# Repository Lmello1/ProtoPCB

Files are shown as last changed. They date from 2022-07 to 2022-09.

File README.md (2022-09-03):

# ProtoPCB

Business card PCB and pocket Attiny3227 and LED matrix playground. Powered by a CR2032 battery
<p align="middle">
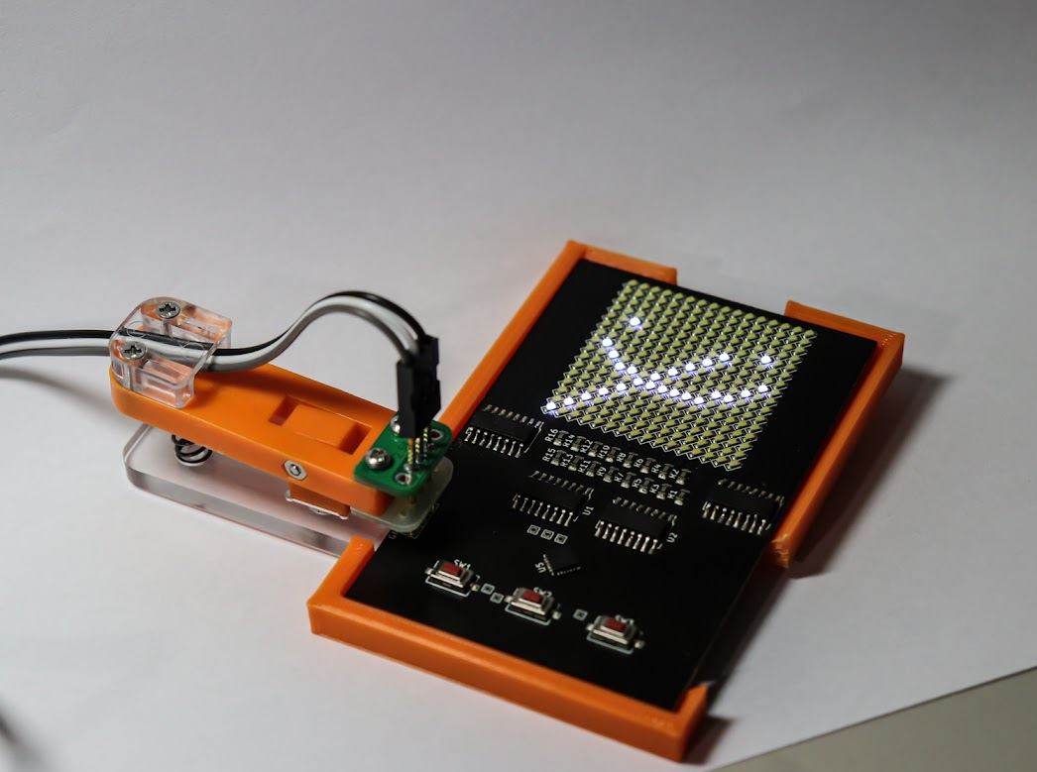
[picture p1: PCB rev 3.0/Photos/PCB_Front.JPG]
  
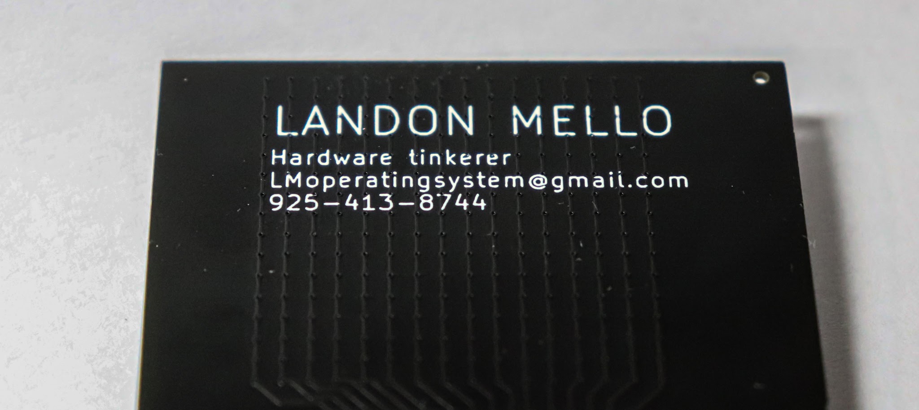
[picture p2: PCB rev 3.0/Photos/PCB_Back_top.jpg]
  
</p>

## Description

A business card PCB based on the ATTINY3227 chipset. Using 4 74HC595D shift registers to drive a 256 LED matrix. With a standard UDPI interface and 3 input buttons the possibilities are endless.
The current code includes various games and demo programs. Please feel free to make your own and share!

NOTE: Shift register U3 is reversed for easier routing.

## Current programs
* Snake

## Coming soon
* Pong
* Tic Tac Toe
* Tetris

## LED matrix info
```
                 led matrix data flow
attiny3227
V
\_________>_______________________>______________________
         U1                      U2                      \
 ____________________    ____________________             |
/                    \  /                    \            |
X  X  X  X  X  X  X  X  X  X  X  X  X  X  X  X \          |
X  X  X  X  X  X  X  X  X  X  X  X  X  X  X  X |          |
X  X  X  X  X  X  X  X  X  X  X  X  X  X  X  X |          |
X  X  X  X  X  X  X  X  X  X  X  X  X  X  X  X |---- U3---V--(REVERSED)
X  X  X  X  X  X  X  X  X  X  X  X  X  X  X  X |          |
X  X  X  X  X  X  X  X  X  X  X  X  X  X  X  X |          |
X  X  X  X  X  X  X  X  X  X  X  X  X  X  X  X |          |
X  X  X  X  X  X  X  X  X  X  X  X  X  X  X  X /          |
X  X  X  X  X  X  X  X  X  X  X  X  X  X  X  X \          |
X  X  X  X  X  X  X  X  X  X  X  X  X  X  X  X |          |
X  X  X  X  X  X  X  X  X  X  X  X  X  X  X  X |          |
X  X  X  X  X  X  X  X  X  X  X  X  X  X  X  X |---- U4   V
X  X  X  X  X  X  X  X  X  X  X  X  X  X  X  X |          |
X  X  X  X  X  X  X  X  X  X  X  X  X  X  X  X |          |
X  X  X  X  X  X  X  X  X  X  X  X  X  X  X  X |          |
X  X  X  X  X  X  X  X  X  X  X  X  X  X  X  X /          *
```

## PCB Revision History
* Rev 1.0 - 1st working version (Do not recreate-one shorted track) NOTE: Removed from github

* Rev 2.0 - Vertical PCB format and visual improvements. Changed foorptints for shift registers

* Rev 3.0 - CR2032 battery holder added for the back, Track routing improvements

## Creators

Landon Mello
[@Landon_Mello](https://twitter.com/Landon_Mello_)

Ben Liebmann

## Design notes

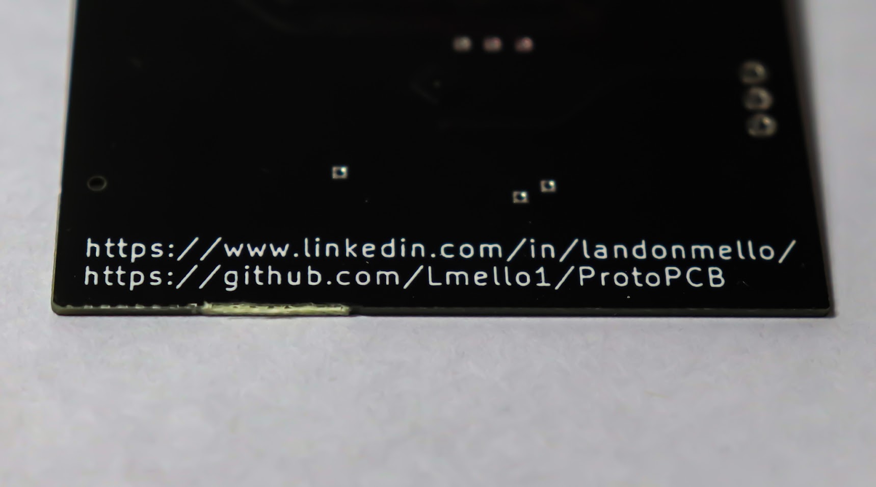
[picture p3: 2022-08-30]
PCB rev 3.0/Photos/PCB_Back_bottom.jpg

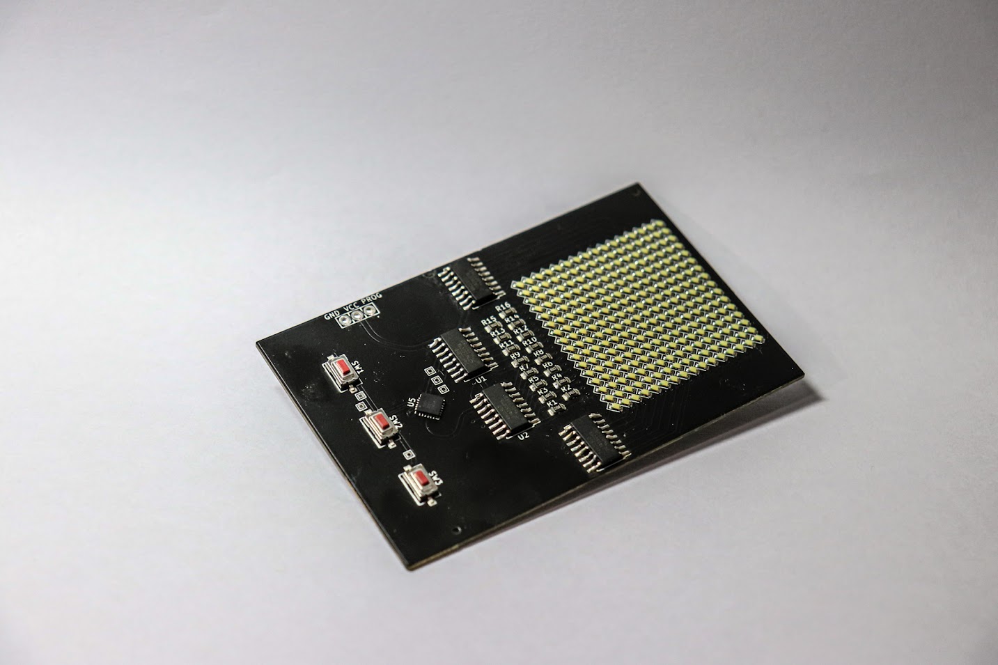
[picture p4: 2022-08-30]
PCB rev 3.0/Photos/PCB_Front_off.JPG

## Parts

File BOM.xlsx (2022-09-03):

 | INV # | Part # | Description | Quantity | Price per |  | Total |  |  |  | INV # | Part # | Description | Quantity | Price per | Total
1 |  | ATTINY3227-MU-ND | Main processer | 1 | 1.772 |  | 1.772 |  |  | 1 |  | ATSAMD20E15B-MU | Main processer mouser | 1 | 2.2896 | 2.2896
2 |  | 74HC595D | Shift registers | 4 | 0.2164 |  | 0.8656 |  |  | 2 |  | 74HC595D | Shift registers | 4 | 0.2164 | 0.8656
3 |  | LED | From china (20k bulk price with shipping) | 256 | 0.00545 |  | 1.3952 |  |  | 3 |  | LED | From china (20k bulk price with shipping) | 256 | 0.00545 | 1.3952
4 |  | 220 ohm resistor |  | 16 | 0.0018 |  | 0.0288 |  |  | 4 |  | 220 ohm resistor |  | 16 | 0.0018 | 0.0288
5 |  | Pushbuttons |  | 3 | 0.0473 |  | 0.1419 |  |  | 5 |  | Pushbuttons |  | 3 | 0.0473 | 0.1419
6 |  |  |  |  |  |  | 0 |  |  | 6 |  |  |  |  |  | 0
7 |  |  |  |  |  |  | 0 |  |  | 7 |  |  |  |  |  | 0
8 |  | PCB |  | 1 | 1.096 |  | 1.096 |  |  | 8 |  | PCB |  | 1 | 1.096 | 1.096
9 |  |  |  |  |  |  | 0 |  |  | 9 |  |  |  |  |  | 0
10 |  |  |  |  |  |  | 0 |  |  | 10 |  |  |  |  |  | 0
11 |  |  |  |  |  |  | 0 |  |  | 11 |  |  |  |  |  | 0
12 |  |  |  |  |  |  | 0 |  |  | 12 |  |  |  |  |  | 0
13 |  |  |  |  |  |  | 0 |  |  | 13 |  |  |  |  |  | 0
14 |  |  |  |  |  |  | 0 |  |  | 14 |  |  |  |  |  | 0
15 |  |  |  |  |  |  | 0 |  |  | 15 |  |  |  |  |  | 0
 |  |  |  |  |  |  | 0 |  |  |  |  |  |  |  |  | 0
 |  |  |  |  |  |  | 5.2995 |  |  |  |  |  |  |  |  | 5.8171
 |  |  | PRICES INCLUDE SHIPPING
 |  |  | Total cost/ cost per unit calculator
 |  |  | Name | Quantity | indv. Cost | Shipping |  | Cost per part | Total cost
1 |  | CPU | 556-ATSAMD20E15B-MU | 25 | 1.97 | 7.99 |  | 2.2896 | 57.24
2 |  | LED | 0603 white LED | 20000 | 0.0035 | 39 |  | 0.00545 | 109
3 |  | SHIFT REGISTERS |  |  |  |  |  | #DIV/0! | 0
4 |  | RESISTOR |  |  |  |  |  | #DIV/0! | 0
5 |  | BUTTONS |  |  |  |  |  | #DIV/0! | 0
6 |  | PCB |  |  |  |  |  | #DIV/0! | 0
7 |  |  |  |  |  |  |  | #DIV/0! | 0
8 |  |  |  |  |  |  |  | #DIV/0! | 0
9 |  |  |  |  |  |  |  | #DIV/0! | 0
10 |  |  |  |  |  |  |  | #DIV/0! | 0
11
12
13
14
15
16
17

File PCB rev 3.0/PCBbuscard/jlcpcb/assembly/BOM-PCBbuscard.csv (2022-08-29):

Comment | Designator | Footprint | LCSC
220 | R1,R10,R11,R12,R13,R14,R15,R16,R2,R3,R4,R5,R6,R7,R8,R9 | R_0805_2012Metric_Pad1.20x1.40mm_HandSolder | C17557
LED | D1,D10,D100,D101,D102,D103,D104,D105,D106,D107,D108,D109,D11,D110,D111,D112,D113,D114,D115,D116,D117,D118,D119,D12,D120,D121,D122,D123,D124,D125,D126,D127,D128,D129,D13,D130,D131,D132,D133,D134,D135,D136,D137,D138,D139,D14,D140,D141,D142,D143,D144,D145,D146,D147,D148,D149,D15,D150,D151,D152,D153,D154,D155,D156,D157,D158,D159,D16,D160,D161,D162,D163,D164,D165,D166,D167,D168,D169,D17,D170,D171,D172,D173,D174,D175,D176,D177,D178,D179,D18,D180,D181,D182,D183,D184,D185,D186,D187,D188,D189,D19,D190,D191,D192,D193,D194,D195,D196,D197,D198,D199,D2,D20,D200,D201,D202,D203,D204,D205,D206,D207,D208,D209,D21,D210,D211,D212,D213,D214,D215,D216,D217,D218,D219,D22,D220,D221,D222,D223,D224,D225,D226,D227,D228,D229,D23,D230,D231,D232,D233,D234,D235,D236,D237,D238,D239,D24,D240,D241,D242,D243,D244,D245,D246,D247,D248,D249,D25,D250,D251,D252,D253,D254,D255,D256,D26,D27,D28,D29,D3,D30,D31,D32,D33,D34,D35,D36,D37,D38,D39,D4,D40,D41,D42,D43,D44,D45,D46,D47,D48,D49,D5,D50,D51,D52,D53,D54,D55,D56,D57,D58,D59,D6,D60,D61,D62,D63,D64,D65,D66,D67,D68,D69,D7,D70,D71,D72,D73,D74,D75,D76,D77,D78,D79,D8,D80,D81,D82,D83,D84,D85,D86,D87,D88,D89,D9,D90,D91,D92,D93,D94,D95,D96,D97,D98,D99 | LED_0603_1608Metric_no_text | C2290
SW_Push | SW1,SW2,SW3 | SW_DIP_SPSTx01_Slide_6.7x4.1mm_W6.73mm_P2.54mm_LowProfile_JPin | C354942
74HC595 | U4 | SOIC127P600X175-16N
74HC595 | U1 | SOIC127P600X175-16N
74HC595 | U3 | SOIC127P600X175-16N
74HC595 | U2 | SOIC127P600X175-16N
ATtiny3217-M | U5 | QFN-24-1EP_4x4mm_P0.5mm_EP2.6x2.6mm_ThermalVias
TestPoint_Probe | TP9 | TestPoint_THTPad_1.0x1.0mm_Drill0.5mm
TestPoint_Probe | TP8 | TestPoint_THTPad_1.0x1.0mm_Drill0.5mm
TestPoint_Probe | TP7 | TestPoint_THTPad_1.0x1.0mm_Drill0.5mm
TestPoint_Probe | TP6 | TestPoint_THTPad_1.0x1.0mm_Drill0.5mm
TestPoint_Probe | TP5 | TestPoint_THTPad_1.0x1.0mm_Drill0.5mm
TestPoint_Probe | TP4 | TestPoint_THTPad_1.0x1.0mm_Drill0.5mm
BAT | U6 | BATHLD001

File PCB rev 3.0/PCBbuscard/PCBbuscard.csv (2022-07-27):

Id | Designator | Package | Quantity | Designation | Supplier and ref
1 | J18,J15,J14,J7 | PinSocket_1x06_P1.27mm_Vertical | 4 | Conn_01x06_Female
2 | J17 | PinHeader_1x07_P2.54mm_Vertical | 1 | VCC
3 | J16 | PinHeader_1x07_P2.54mm_Vertical | 1 | GND
4 | J13,J12,J11,J10,J9,J8,J6,J5,J4,J3,J2,J1 | PinHeader_1x04_P2.54mm_Vertical | 12 | Conn_01x04_Female
5 | D190,D7,D32,D69,D36,D129,D155,D132,D227,D28,D58,D181,D163,D204,D235,D11,D164,D84,D38,D225,D186,D191,D1,D120,D18,D184,D171,D65,D26,D57,D195,D97,D168,D179,D72,D220,D143,D8,D112,D255,D252,D60,D165,D148,D35,D210,D152,D105,D150,D228,D238,D153,D248,D200,D250,D211,D182,D122,D128,D202,D223,D208,D6,D149,D2,D118,D70,D170,D131,D147,D61,D175,D139,D240,D127,D50,D205,D154,D90,D229,D16,D251,D41,D124,D3,D46,D206,D162,D13,D207,D233,D103,D83,D29,D123,D55,D87,D231,D62,D116,D31,D88,D161,D85,D215,D203,D101,D10,D27,D114,D253,D82,D109,D236,D226,D232,D74,D67,D33,D140,D71,D66,D104,D209,D78,D136,D99,D102,D111,D135,D37,D241,D53,D15,D4,D100,D187,D56,D24,D166,D249,D68,D224,D158,D246,D75,D119,D198,D176,D9,D137,D43,D63,D174,D92,D185,D142,D193,D40,D244,D94,D243,D216,D156,D14,D239,D177,D245,D230,D222,D51,D167,D76,D138,D77,D23,D81,D172,D213,D247,D146,D44,D79,D145,D126,D256,D42,D107,D160,D95,D242,D52,D221,D117,D108,D110,D86,D30,D54,D197,D183,D237,D234,D22,D188,D80,D254,D5,D196,D113,D219,D73,D25,D214,D141,D91,D159,D89,D199,D144,D39,D189,D106,D212,D180,D96,D45,D20,D21,D157,D218,D64,D19,D133,D17,D173,D115,D48,D47,D151,D49,D93,D34,D169,D192,D130,D134,D98,D194,D125,D178,D12,D121,D59,D217,D201 | LED_0201_0603Metric NOTEXT | 256 | LED
6 | R12,R7,R2,R9,R11,R6,R8,R13,R10,R3,R5,R1,R4,R15,R14,R16 | R_0805_2012Metric_Pad1.20x1.40mm_HandSolder | 16 | 220
7 | U4,U1,U3,U2 | SOIC-16W_5.3x10.2mm_P1.27mm | 4 | 74HC595
8 | TP3 | TestPoint_Plated_Hole_D2.0mm | 1 | UPDI
9 | SW2,SW3,SW1 | SW_DIP_SPSTx01_Slide_6.7x4.1mm_W6.73mm_P2.54mm_LowProfile_JPin | 3 | SW_Push
10 | TP2 | TestPoint_Plated_Hole_D2.0mm | 1 | GND
11 | U5 | QFN-24-1EP_4x4mm_P0.5mm_EP2.6x2.6mm_ThermalVias | 1 | ATtiny3217-M
12 | TP1 | TestPoint_Plated_Hole_D2.0mm | 1 | VCC

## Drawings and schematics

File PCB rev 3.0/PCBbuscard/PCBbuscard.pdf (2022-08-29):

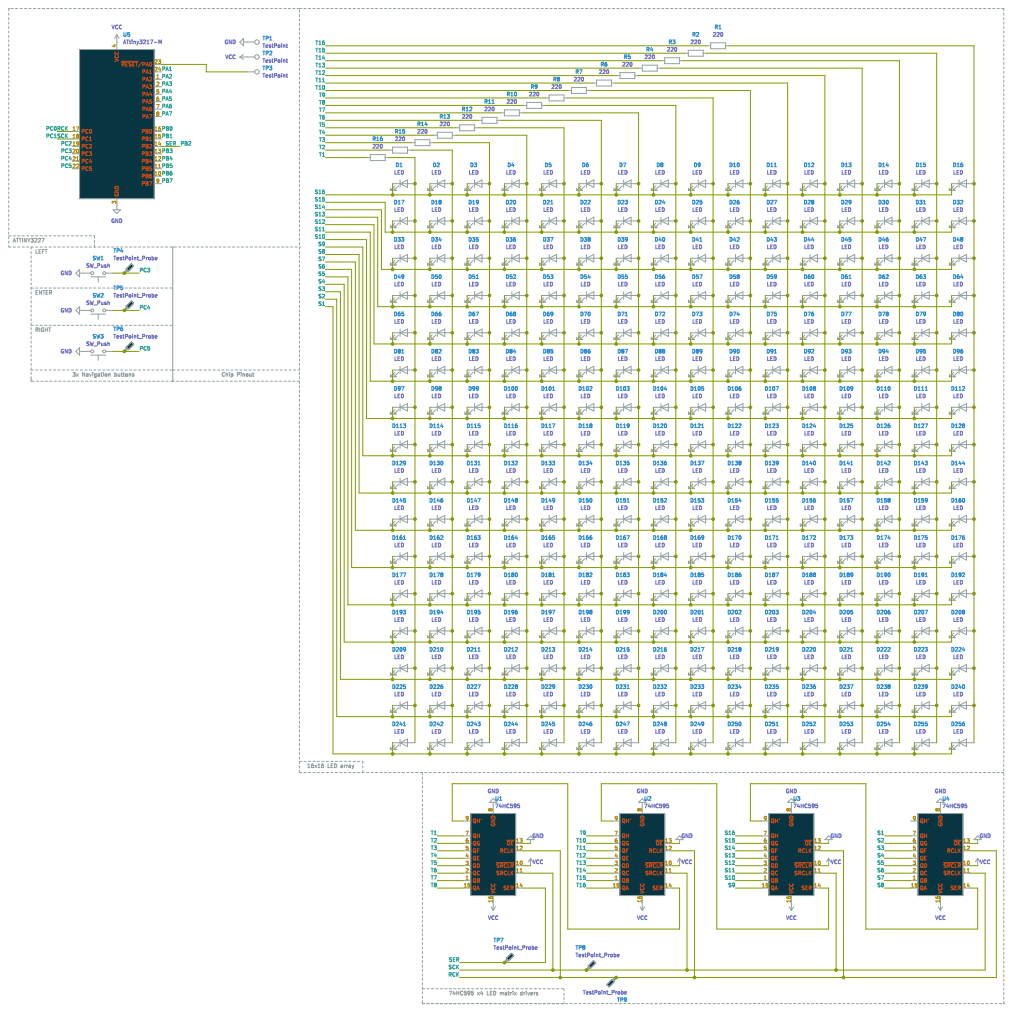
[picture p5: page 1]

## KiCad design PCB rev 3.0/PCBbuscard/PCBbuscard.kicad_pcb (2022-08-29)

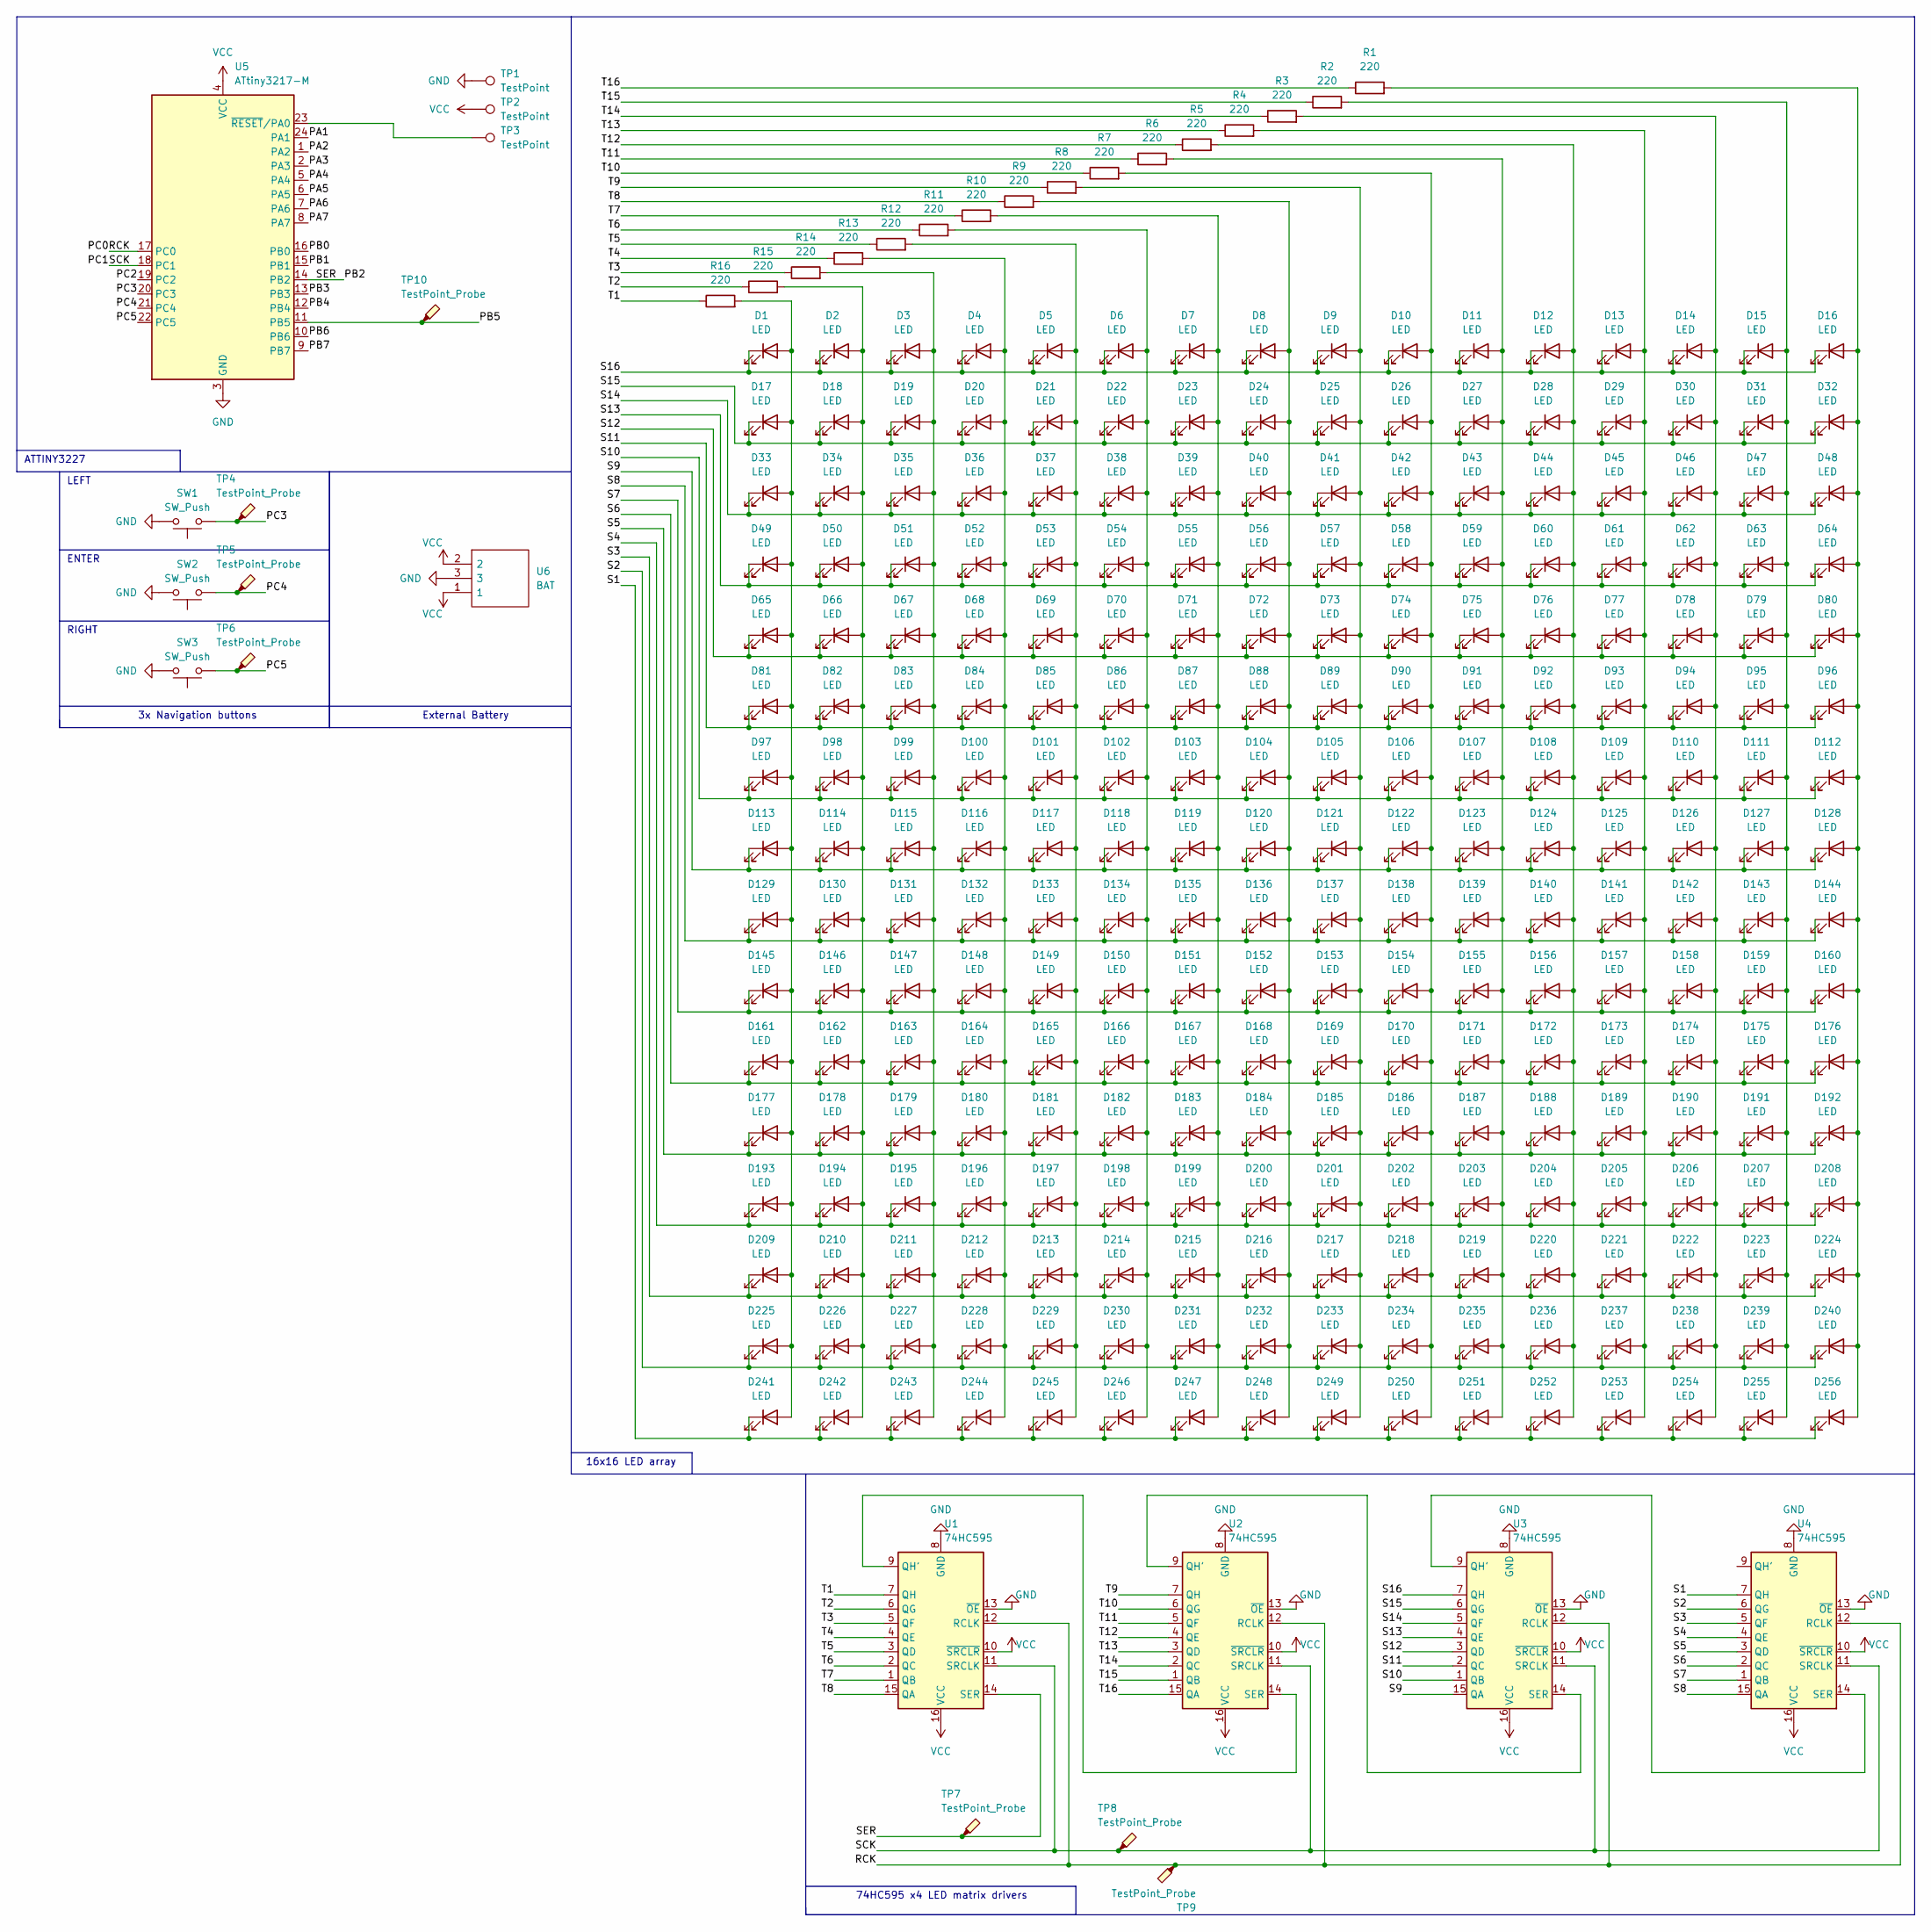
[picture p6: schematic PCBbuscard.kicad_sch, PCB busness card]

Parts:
D1, D2, D3, D4, D5, D6, D7, D8, D9, D10, D11, D12, D13, D14, D15, D16, D17, D18, D19, D20, D21, D22, D23, D24, D25, D26, D27, D28, D29, D30, D31, D32, D33, D34, D35, D36, D37, D38, D39, D40, D41, D42, D43, D44, D45, D46, D47, D48, D49, D50, D51, D52, D53, D54, D55, D56, D57, D58, D59, D60, D61, D62, D63, D64, D65, D66, D67, D68, D69, D70, D71, D72, D73, D74, D75, D76, D77, D78, D79, D80, D81, D82, D83, D84, D85, D86, D87, D88, D89, D90, D91, D92, D93, D94, D95, D96, D97, D98, D99, D100, D101, D102, D103, D104, D105, D106, D107, D108, D109, D110, D111, D112, D113, D114, D115, D116, D117, D118, D119, D120, D121, D122, D123, D124, D125, D126, D127, D128, D129, D130, D131, D132, D133, D134, D135, D136, D137, D138, D139, D140, D141, D142, D143, D144, D145, D146, D147, D148, D149, D150, D151, D152, D153, D154, D155, D156, D157, D158, D159, D160, D161, D162, D163, D164, D165, D166, D167, D168, D169, D170, D171, D172, D173, D174, D175, D176, D177, D178, D179, D180, D181, D182, D183, D184, D185, D186, D187, D188, D189, D190, D191, D192, D193, D194, D195, D196, D197, D198, D199, D200, D201, D202, D203, D204, D205, D206, D207, D208, D209, D210, D211, D212, D213, D214, D215, D216, D217, D218, D219, D220, D221, D222, D223, D224, D225, D226, D227, D228, D229, D230, D231, D232, D233, D234, D235, D236, D237, D238, D239, D240, D241, D242, D243, D244, D245, D246, D247, D248, D249, D250, D251, D252, D253, D254, D255, D256: LED; LED_0603_1608Metric_no_text
R1, R2, R3, R4, R5, R6, R7, R8, R9, R10, R11, R12, R13, R14, R15, R16: 220; R_0805_2012Metric_Pad1.20x1.40mm_HandSolder
SW1, SW2, SW3: SW_Push; SW_DIP_SPSTx01_Slide_6.7x4.1mm_W6.73mm_P2.54mm_LowProfile_J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
TP1, TP2, TP3: TestPoint; Pin_D1.1mm_L8.5mm_W2.5mm_FlatFork
TP4, TP5, TP6, TP7, TP8, TP9: TestPoint_Probe; TestPoint_THTPad_1.0x1.0mm_Drill0.5mm
TP10: TestPoint_Probe; Pin_D1.1mm_L8.5mm_W2.5mm_FlatFork
U1, U2, U3, U4: 74HC595; SOIC127P600X175-16N
U5: ATtiny3217-M; QFN-24-1EP_4x4mm_P0.5mm_EP2.6x2.6mm_ThermalVias
U6: BAT; BATHLD001; Mouser Part Number 712-BAT-HLD-001

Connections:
/PA1: U5.24 (PA1)
/PA2: U5.1 (PA2)
/PA3: U5.2 (PA3)
/PA4: U5.5 (PA4)
/PA5: U5.6 (PA5)
/PA6: U5.7 (PA6)
/PA7: U5.8 (PA7)
/PB0: U5.16 (PB0)
/PB1: U5.15 (PB1)
/PB2: TP7.1, U1.14 (SER), U5.14 (PB2)
/PB3: U5.13 (PB3)
/PB4: U5.12 (PB4)
/PB5: TP10.1, U5.11 (PB5); also elsewhere on the board
/PB6: U5.10 (PB6)
/PB7: U5.9 (PB7)
/PC0: TP9.1, U1.12 (RCLK), U2.12 (RCLK), U3.12 (RCLK), U4.12 (RCLK), U5.17 (PC0)
/PC1: TP8.1, U1.11 (SRCLK), U2.11 (SRCLK), U3.11 (SRCLK), U4.11 (SRCLK), U5.18 (PC1)
/PC2: U5.19 (PC2)
/PC3: SW1.1, TP4.1, U5.20 (PC3)
/PC4: SW2.1, TP5.1, U5.21 (PC4)
/PC5: SW3.1, TP6.1, U5.22 (PC5)
/S1: D241.1 (K), D242.1 (K), D243.1 (K), D244.1 (K), D245.1 (K), D246.1 (K), D247.1 (K), D248.1 (K), D249.1 (K), D250.1 (K), D251.1 (K), D252.1 (K), D253.1 (K), D254.1 (K), D255.1 (K), D256.1 (K), U4.7 (QH)
/S2: D225.1 (K), D226.1 (K), D227.1 (K), D228.1 (K), D229.1 (K), D230.1 (K), D231.1 (K), D232.1 (K), D233.1 (K), D234.1 (K), D235.1 (K), D236.1 (K), D237.1 (K), D238.1 (K), D239.1 (K), D240.1 (K), U4.6 (QG)
/S3: D209.1 (K), D210.1 (K), D211.1 (K), D212.1 (K), D213.1 (K), D214.1 (K), D215.1 (K), D216.1 (K), D217.1 (K), D218.1 (K), D219.1 (K), D220.1 (K), D221.1 (K), D222.1 (K), D223.1 (K), D224.1 (K), U4.5 (QF)
/S4: D193.1 (K), D194.1 (K), D195.1 (K), D196.1 (K), D197.1 (K), D198.1 (K), D199.1 (K), D200.1 (K), D201.1 (K), D202.1 (K), D203.1 (K), D204.1 (K), D205.1 (K), D206.1 (K), D207.1 (K), D208.1 (K), U4.4 (QE)
/S5: D177.1 (K), D178.1 (K), D179.1 (K), D180.1 (K), D181.1 (K), D182.1 (K), D183.1 (K), D184.1 (K), D185.1 (K), D186.1 (K), D187.1 (K), D188.1 (K), D189.1 (K), D190.1 (K), D191.1 (K), D192.1 (K), U4.3 (QD)
/S6: D161.1 (K), D162.1 (K), D163.1 (K), D164.1 (K), D165.1 (K), D166.1 (K), D167.1 (K), D168.1 (K), D169.1 (K), D170.1 (K), D171.1 (K), D172.1 (K), D173.1 (K), D174.1 (K), D175.1 (K), D176.1 (K), U4.2 (QC)
/S7: D145.1 (K), D146.1 (K), D147.1 (K), D148.1 (K), D149.1 (K), D150.1 (K), D151.1 (K), D152.1 (K), D153.1 (K), D154.1 (K), D155.1 (K), D156.1 (K), D157.1 (K), D158.1 (K), D159.1 (K), D160.1 (K), U4.1 (QB)
/S8: D129.1 (K), D130.1 (K), D131.1 (K), D132.1 (K), D133.1 (K), D134.1 (K), D135.1 (K), D136.1 (K), D137.1 (K), D138.1 (K), D139.1 (K), D140.1 (K), D141.1 (K), D142.1 (K), D143.1 (K), D144.1 (K), U4.15 (QA)
/S9: D113.1 (K), D114.1 (K), D115.1 (K), D116.1 (K), D117.1 (K), D118.1 (K), D119.1 (K), D120.1 (K), D121.1 (K), D122.1 (K), D123.1 (K), D124.1 (K), D125.1 (K), D126.1 (K), D127.1 (K), D128.1 (K), U3.15 (QA)
/S10: D97.1 (K), D98.1 (K), D99.1 (K), D100.1 (K), D101.1 (K), D102.1 (K), D103.1 (K), D104.1 (K), D105.1 (K), D106.1 (K), D107.1 (K), D108.1 (K), D109.1 (K), D110.1 (K), D111.1 (K), D112.1 (K), U3.1 (QB)
/S11: D81.1 (K), D82.1 (K), D83.1 (K), D84.1 (K), D85.1 (K), D86.1 (K), D87.1 (K), D88.1 (K), D89.1 (K), D90.1 (K), D91.1 (K), D92.1 (K), D93.1 (K), D94.1 (K), D95.1 (K), D96.1 (K), U3.2 (QC)
/S12: D65.1 (K), D66.1 (K), D67.1 (K), D68.1 (K), D69.1 (K), D70.1 (K), D71.1 (K), D72.1 (K), D73.1 (K), D74.1 (K), D75.1 (K), D76.1 (K), D77.1 (K), D78.1 (K), D79.1 (K), D80.1 (K), U3.3 (QD)
/S13: D49.1 (K), D50.1 (K), D51.1 (K), D52.1 (K), D53.1 (K), D54.1 (K), D55.1 (K), D56.1 (K), D57.1 (K), D58.1 (K), D59.1 (K), D60.1 (K), D61.1 (K), D62.1 (K), D63.1 (K), D64.1 (K), U3.4 (QE)
/S14: D33.1 (K), D34.1 (K), D35.1 (K), D36.1 (K), D37.1 (K), D38.1 (K), D39.1 (K), D40.1 (K), D41.1 (K), D42.1 (K), D43.1 (K), D44.1 (K), D45.1 (K), D46.1 (K), D47.1 (K), D48.1 (K), U3.5 (QF)
/S15: D17.1 (K), D18.1 (K), D19.1 (K), D20.1 (K), D21.1 (K), D22.1 (K), D23.1 (K), D24.1 (K), D25.1 (K), D26.1 (K), D27.1 (K), D28.1 (K), D29.1 (K), D30.1 (K), D31.1 (K), D32.1 (K), U3.6 (QG)
/S16: D1.1 (K), D2.1 (K), D3.1 (K), D4.1 (K), D5.1 (K), D6.1 (K), D7.1 (K), D8.1 (K), D9.1 (K), D10.1 (K), D11.1 (K), D12.1 (K), D13.1 (K), D14.1 (K), D15.1 (K), D16.1 (K), U3.7 (QH)
/T1: R16.1, U1.7 (QH)
/T2: R15.1, U1.6 (QG)
/T3: R14.1, U1.5 (QF)
/T4: R13.1, U1.4 (QE)
/T5: R12.1, U1.3 (QD)
/T6: R11.1, U1.2 (QC)
/T7: R10.1, U1.1 (QB)
/T8: R9.1, U1.15 (QA)
/T9: R8.1, U2.7 (QH)
/T10: R7.1, U2.6 (QG)
/T11: R6.1, U2.5 (QF)
/T12: R5.1, U2.4 (QE)
/T13: R4.1, U2.3 (QD)
/T14: R3.1, U2.2 (QC)
/T15: R2.1, U2.1 (QB)
/T16: R1.1, U2.15 (QA)
GND: SW1.2, SW2.2, SW3.2, TP1.1, U1.8 (GND), U1.13 (~OE), U2.8 (GND), U2.13 (~OE), U3.8 (GND), U3.13 (~OE), U4.8 (GND), U4.13 (~OE), U5.3 (GND), U5.25 (GND), U6.3; also elsewhere on the board
unnamed: D1.2 (A), D17.2 (A), D33.2 (A), D49.2 (A), D65.2 (A), D81.2 (A), D97.2 (A), D113.2 (A), D129.2 (A), D145.2 (A), D161.2 (A), D177.2 (A), D193.2 (A), D209.2 (A), D225.2 (A), D241.2 (A), R16.2
unnamed: D10.2 (A), D26.2 (A), D42.2 (A), D58.2 (A), D74.2 (A), D90.2 (A), D106.2 (A), D122.2 (A), D138.2 (A), D154.2 (A), D170.2 (A), D186.2 (A), D202.2 (A), D218.2 (A), D234.2 (A), D250.2 (A), R7.2
unnamed: D4.2 (A), D20.2 (A), D36.2 (A), D52.2 (A), D68.2 (A), D84.2 (A), D100.2 (A), D116.2 (A), D132.2 (A), D148.2 (A), D164.2 (A), D180.2 (A), D196.2 (A), D212.2 (A), D228.2 (A), D244.2 (A), R13.2
unnamed: D5.2 (A), D21.2 (A), D37.2 (A), D53.2 (A), D69.2 (A), D85.2 (A), D101.2 (A), D117.2 (A), D133.2 (A), D149.2 (A), D165.2 (A), D181.2 (A), D197.2 (A), D213.2 (A), D229.2 (A), D245.2 (A), R12.2
unnamed: D6.2 (A), D22.2 (A), D38.2 (A), D54.2 (A), D70.2 (A), D86.2 (A), D102.2 (A), D118.2 (A), D134.2 (A), D150.2 (A), D166.2 (A), D182.2 (A), D198.2 (A), D214.2 (A), D230.2 (A), D246.2 (A), R11.2
unnamed: D7.2 (A), D23.2 (A), D39.2 (A), D55.2 (A), D71.2 (A), D87.2 (A), D103.2 (A), D119.2 (A), D135.2 (A), D151.2 (A), D167.2 (A), D183.2 (A), D199.2 (A), D215.2 (A), D231.2 (A), D247.2 (A), R10.2
unnamed: D8.2 (A), D24.2 (A), D40.2 (A), D56.2 (A), D72.2 (A), D88.2 (A), D104.2 (A), D120.2 (A), D136.2 (A), D152.2 (A), D168.2 (A), D184.2 (A), D200.2 (A), D216.2 (A), D232.2 (A), D248.2 (A), R9.2
unnamed: D9.2 (A), D25.2 (A), D41.2 (A), D57.2 (A), D73.2 (A), D89.2 (A), D105.2 (A), D121.2 (A), D137.2 (A), D153.2 (A), D169.2 (A), D185.2 (A), D201.2 (A), D217.2 (A), D233.2 (A), D249.2 (A), R8.2
unnamed: D11.2 (A), D27.2 (A), D43.2 (A), D59.2 (A), D75.2 (A), D91.2 (A), D107.2 (A), D123.2 (A), D139.2 (A), D155.2 (A), D171.2 (A), D187.2 (A), D203.2 (A), D219.2 (A), D235.2 (A), D251.2 (A), R6.2
unnamed: D12.2 (A), D28.2 (A), D44.2 (A), D60.2 (A), D76.2 (A), D92.2 (A), D108.2 (A), D124.2 (A), D140.2 (A), D156.2 (A), D172.2 (A), D188.2 (A), D204.2 (A), D220.2 (A), D236.2 (A), D252.2 (A), R5.2
unnamed: D13.2 (A), D29.2 (A), D45.2 (A), D61.2 (A), D77.2 (A), D93.2 (A), D109.2 (A), D125.2 (A), D141.2 (A), D157.2 (A), D173.2 (A), D189.2 (A), D205.2 (A), D221.2 (A), D237.2 (A), D253.2 (A), R4.2
unnamed: D14.2 (A), D30.2 (A), D46.2 (A), D62.2 (A), D78.2 (A), D94.2 (A), D110.2 (A), D126.2 (A), D142.2 (A), D158.2 (A), D174.2 (A), D190.2 (A), D206.2 (A), D222.2 (A), D238.2 (A), D254.2 (A), R3.2
unnamed: D15.2 (A), D31.2 (A), D47.2 (A), D63.2 (A), D79.2 (A), D95.2 (A), D111.2 (A), D127.2 (A), D143.2 (A), D159.2 (A), D175.2 (A), D191.2 (A), D207.2 (A), D223.2 (A), D239.2 (A), D255.2 (A), R2.2
unnamed: D16.2 (A), D32.2 (A), D48.2 (A), D64.2 (A), D80.2 (A), D96.2 (A), D112.2 (A), D128.2 (A), D144.2 (A), D160.2 (A), D176.2 (A), D192.2 (A), D208.2 (A), D224.2 (A), D240.2 (A), D256.2 (A), R1.2
unnamed: D2.2 (A), D18.2 (A), D34.2 (A), D50.2 (A), D66.2 (A), D82.2 (A), D98.2 (A), D114.2 (A), D130.2 (A), D146.2 (A), D162.2 (A), D178.2 (A), D194.2 (A), D210.2 (A), D226.2 (A), D242.2 (A), R15.2
unnamed: D3.2 (A), D19.2 (A), D35.2 (A), D51.2 (A), D67.2 (A), D83.2 (A), D99.2 (A), D115.2 (A), D131.2 (A), D147.2 (A), D163.2 (A), D179.2 (A), D195.2 (A), D211.2 (A), D227.2 (A), D243.2 (A), R14.2
unnamed 70: TP3.1, U5.23 (~RESET/PA0); also elsewhere on the board
unnamed: U1.9 (QH'), U2.14 (SER)
unnamed: U2.9 (QH'), U3.14 (SER)
unnamed: U3.9 (QH'), U4.14 (SER)
VCC: TP2.1, U1.10 (~SRCLR), U1.16 (VCC), U2.10 (~SRCLR), U2.16 (VCC), U3.10 (~SRCLR), U3.16 (VCC), U4.10 (~SRCLR), U4.16 (VCC), U5.4 (VCC), U6.1, U6.2; also elsewhere on the board

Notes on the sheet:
External Battery
ENTER
RIGHT
3x Navigation buttons
74HC595 x4 LED matrix drivers
16x16 LED array
LEFT
ATTINY3227

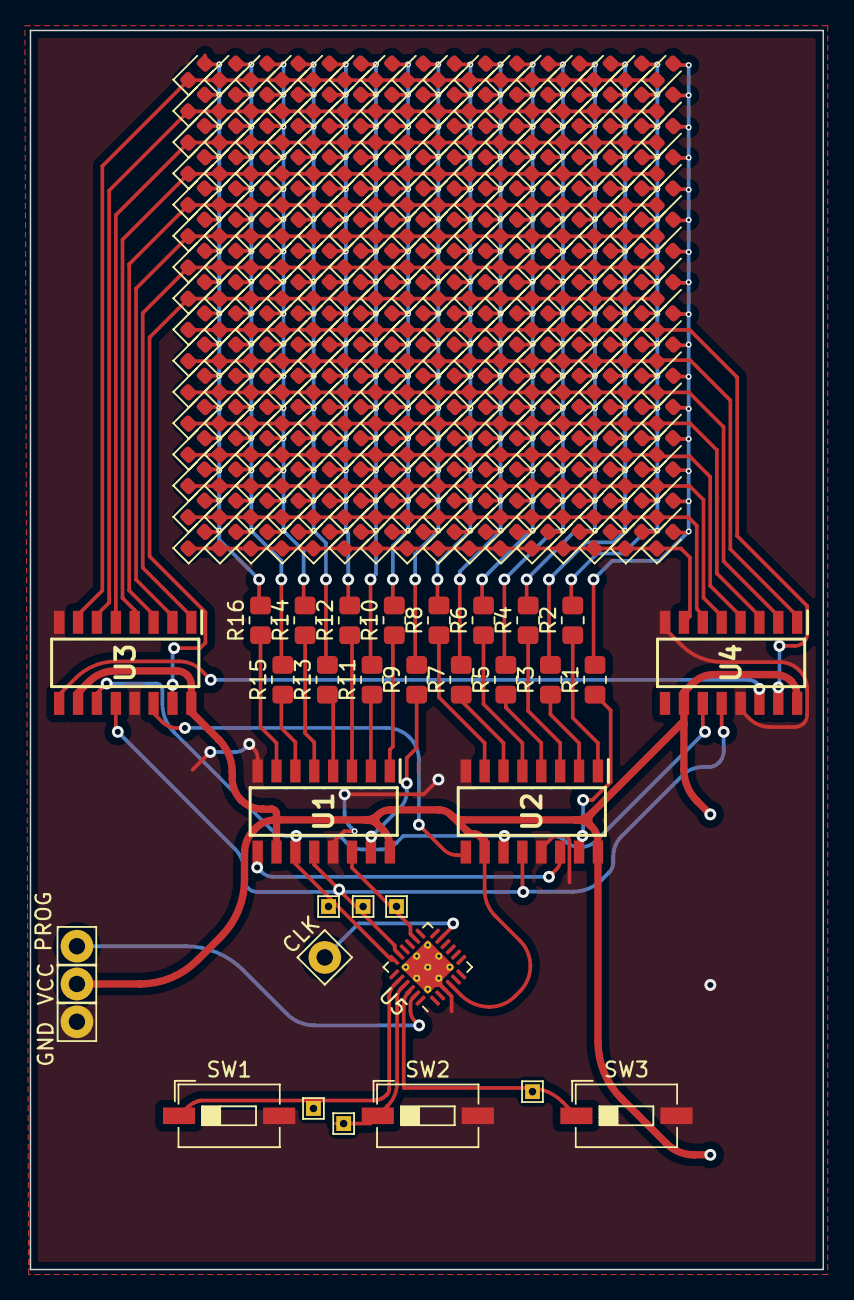
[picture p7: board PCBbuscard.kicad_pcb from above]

Board: 2 copper layers, 53.3 x 83.3 mm, 291 parts (1 on the bottom side), 61 nets.

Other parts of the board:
CLK: TestPoint_Probe; Pin_D1.1mm_L8.5mm_W2.5mm_FlatFork
GND: TestPoint; Pin_D1.1mm_L8.5mm_W2.5mm_FlatFork
PROG: TestPoint; Pin_D1.1mm_L8.5mm_W2.5mm_FlatFork
VCC: TestPoint; Pin_D1.1mm_L8.5mm_W2.5mm_FlatFork

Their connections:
/PB5: CLK.1; also elsewhere on the board
GND: GND.1; also elsewhere on the board
unnamed 70: PROG.1; also elsewhere on the board
VCC: VCC.1; also elsewhere on the board

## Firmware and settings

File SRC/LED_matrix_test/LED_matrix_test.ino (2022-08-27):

#define SNAKE
#include "game.hpp"
#include "matrix.hpp"
#include <Arduino.h>
#include <util/atomic.h>

static constexpr uint8_t BUTTON_1 = 15;
static constexpr uint8_t BUTTON_2 = 16;
static constexpr uint8_t BUTTON_3 = 17;


void setup(void) {
    pinMode(LATCH_PIN, OUTPUT);
    pinMode(CLOCK_PIN, OUTPUT);
    pinMode(DATA_PIN, OUTPUT);
    pinMode(BUTTON_1, INPUT_PULLUP);
    pinMode(BUTTON_2, INPUT_PULLUP);
    pinMode(BUTTON_3, INPUT_PULLUP);
    ATOMIC_BLOCK(ATOMIC_FORCEON) {
        //https://ww1.microchip.com/downloads/en/DeviceDoc/ATtiny3224-3226-3227-Data-Sheet-DS40002345A.pdf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
        TCA0.SINGLE.CTRLA |= 0b00001111;
        TCA0.SINGLE.CMP0 = 1041;
        TCA0.SINGLE.INTCTRL = 0b00010000;
    }

    play();
}

static uint8_t x = 0, y = 0;

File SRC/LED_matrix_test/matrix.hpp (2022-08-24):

#pragma once
#include <stdint.h>

static constexpr uint8_t LATCH_PIN = 12;
static constexpr uint8_t CLOCK_PIN = 13;
static constexpr uint8_t DATA_PIN = 9;


namespace matrix {

/** \brief Constant passed to the `set` function to turn an LED on, so we can eliminate an unneeded bitshift */
static constexpr uint8_t LED_ON = 0b10000000;

/** 
 * How a half of a single row of the LED matrix is stored,
 * here every bit in the number indicates if the LED should be on or off
 */
using rowmask_t = uint8_t;

/** 
 * \brief Buffer containing bitmasks for each row in the matrix display.
 * The reason that 32 uint8_ts are stored instead of 16 uint16_ts is because operations on uint8_ts are atomic,
 * meaning they cannot be interrupted by the screen rendering interrupt. So, we can modify portions of the display buffer without needing an `ATOMIC_BLOCK`
 */
extern volatile matrix::rowmask_t screen_buf[32];

/**
 * Set an LED in the matrix display by (x, y) coordinates
 */
__attribute__((always_inline))
inline void set(uint8_t x, uint8_t y) {
    uint8_t i = y * 2 + (x > 7 ? 1 : 0);
    screen_buf[i] |= (LED_ON >> (x % 8));
}

/**
 * Set or unset an LED in the matrix display by (x, y) coordinates
 */
__attribute__((always_inline))
inline void unset(uint8_t x, uint8_t y) {
    uint8_t i = y * 2 + (x > 7 ? 1 : 0);
    screen_buf[i] &= ~(LED_ON >> (x % 8));
}

/**
 * Set the contents of an entire row to the bitmask specified. Note that this function is **not** atomic and
 * must be surrounded by an `ATOMIC_BLOCK` to ensure no garbled screen data is present
 * \param row The row index from 0-15 inclusive
 * \param val Bitmap of LED values, e.x.: 0b0101010101010101
 */
__attribute__((always_inline))
inline void setrow(uint8_t row, uint16_t val) {
    screen_buf[row * 2 + 1] = (uint8_t)val;
    screen_buf[row * 2] = (uint8_t)(val >> 8);
}

}

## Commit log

2022-07-26 Update formatting + convert constants to constexprs
    -- Identifiers for pin constants converted to SCREAMING_SNAKE_CASE per most C/C++ standard practice
    -- Pin constants converted from `const int`s to `constexpr uint8_t`s more strictly adheres to how modern C++ should define a constant value
2022-07-26 Added timer1 hardware interrupt for asynchronous LED matrix updates
    -- Enabled interrupt on timer1 that displays the value of the current row on the LED matrix
    -- The processor will now constantly update the LED matrix
    -- Note that any mutations to the `matrix_buf` global MUST be in an ATOMIC_BLOCK or with NoIterrupts called, or else the interrupt may be triggered while writing data to the buffer, causing scrambled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
    to appear on the LED matrix
2022-07-26 Updated refresh rate of the LED matrix to be 30hz
2022-07-26 Added testing pattern for the LED matrix
2022-07-27 PCB rev 1.0! (do not use/under heavy development)
    [BOM-PCBbuscard.csv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]
2022-07-27 Corrected timer and display code
    [LED_matrix_test.ino]
2022-07-27 Updated matrix refresh rate to 15hz
2022-07-27 Actually Updated matrix refresh rate to 15hz (prev. commit was 150hz)
2022-07-27 Fixed LED matrix display
    - Fixes LED matrix display control
    [matrix.hpp]
2022-07-27 Fix lower right quadrant display bug, add moving test pattern
    [LED_matrix_test.ino, matrix.hpp]
2022-08-10 Changed timer used for screen rendering interrupts to timer A and update refresh rate
    - Timer A used instead of timer B to use the 1024 clock prescaler only available on timer A
    - Refresh rate changed to 15hz
2022-08-14 Attempted fix for new shift register layout
    [LED_matrix_test.ino]
2022-08-23 Fixed ILLEGAL_MCU_STATE: Running error by updating interrupt source for draw procedure
    [LED_matrix_test.ino]
2022-08-23 Reordered Y axis of LED matrix and partially re-wrote interrupt in assembly
    - LED matrix coordinates now more closely represent standard graph coordinates, e.g. y = 0 is the bottom of the screen, while y = 15 is the top of the screen
    - Rewrite of column bit banging portion of screen rendering interrupt in assembly
    - Rewrite in asm favors speed over size, minimizing branching and cpu cycles at the expense of ~50 bytes of program memory
    - For half the screen, column bits are pushed at the fastest the cpu can possibly switch an IO pin without hardware PWM; i.e. around 8Mhz
2022-08-23 Updated assembly comments, replaced uneeded compare instruction - Assembly comments added + edited existing comments to more accurately reflect what is being achieved - Removed unneeded instruction c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
2022-08-23 Fixed data race in LED matrix buffer by changing millis() source to RTC
    [LED_matrix_test.ino]
2022-08-24 Fully rewrote rendering interrupt handler in assembly
    - Full rewrite in assembly favors speed over size, with manually unrolled loops, etc.
2022-08-29 PCB rev 2.0 update
    [BOM-PCBbuscard.csv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]
2022-08-30 BOM + PCB photos
    [BOM.xlsx]
2022-09-01 fixed rev #
    [BOM-PCBbuscard.csv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]
